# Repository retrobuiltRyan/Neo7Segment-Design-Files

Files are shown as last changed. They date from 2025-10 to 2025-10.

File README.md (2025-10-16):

KiCAD 8.x files created.

A reworked layout of Unexpected Maker's 7SegNeo Display project. Chain these addressable LED modules together to make a large 7-segment display. Control via any micro-controller just like you would control a strip of RGB LEDs. Custom library made by Unexpected Maker.



fart neo7seg good gif
P1100468

Assembly Required:
Each moduled has a resistor footprint at the Data In line. The first module in the chain requires a ~220-330 ohm resistor soldered here. Each moduled next in the chain requires this jumper closed; 0-ohm resistor or just a solder blob.
P1100470 - Copy

Change list: bumped-up passives footprint to 1206, finessed trace/ copper pour layout; slightly larger PCB area, larger mounting holes, decimal place pixel same footprint as all other pixels.
Created some 3D printable mounting brackets to expidite building projects like a clock/scoreboard. 

RGBLEDs: 1568-16347CT-ND or https://www.aliexpress.us/item/3256802466699315.html

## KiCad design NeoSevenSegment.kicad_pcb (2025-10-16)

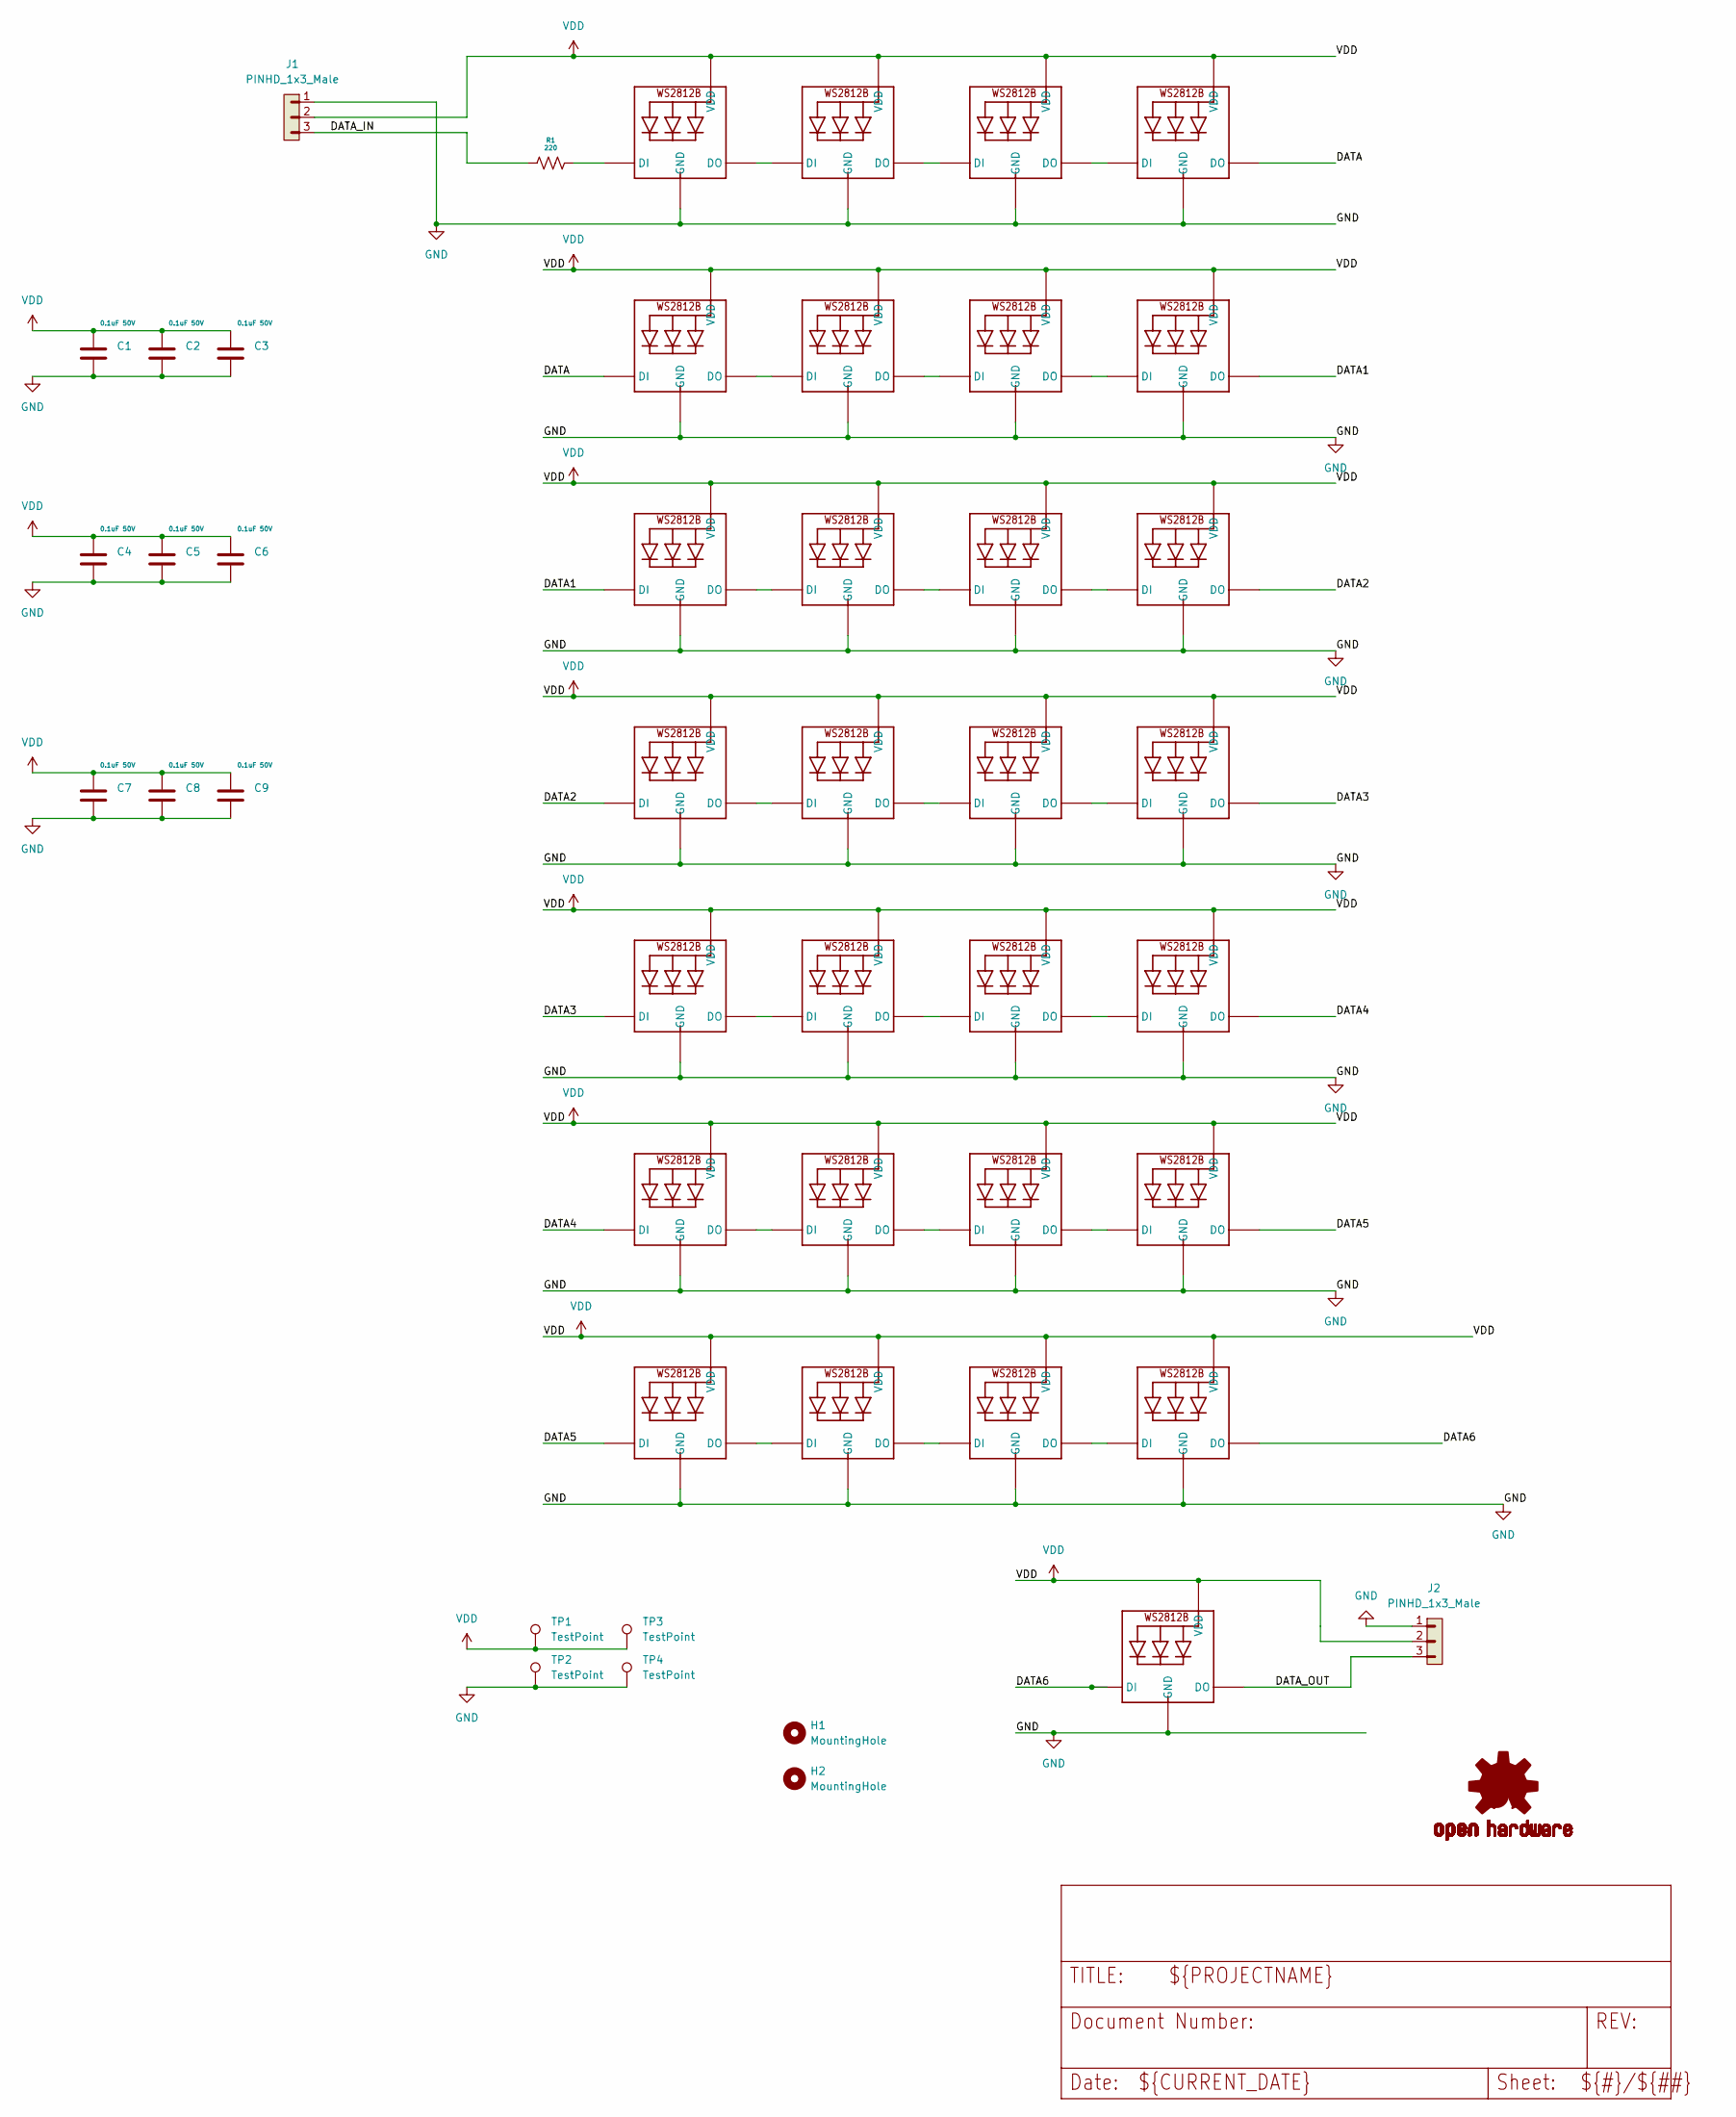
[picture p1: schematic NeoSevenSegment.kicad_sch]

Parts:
C1, C2, C3, C4, C5, C6, C7, C8, C9: 0.1uF 50V; C_1206_3216Metric; DigiKey P/N 1276-1068-1-ND
H1, H2: MountingHole; MountingHole_3.2mm_M3_ISO14580_Pad_TopBottom
J1, J2: PINHD_1x3_Male; PinHeader_1x03_P2.54mm_Vertical
LED1, LED2, LED3, LED4, LED5, LED6, LED7, LED8, LED9, LED10, LED11, LED12, LED13, LED14, LED15, LED16, LED17, LED18, LED19, LED20, LED21, LED22, LED23, LED24, LED25, LED26, LED27, LED28, LED29: WS2812B_5050N; WS2812B-NARROW
LOGO1: OSHW-LOGOM; OSHW-LOGO-M
R1: 220; R_1206_3216Metric; DigiKey P/N 311-220FRCT-ND
TP1, TP2, TP3, TP4: TestPoint; TestPoint_Pad_2.5x2.5mm

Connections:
/DATA: LED4.2-DOUT (DO), LED5.4-DIN (DI)
/DATA1: LED8.2-DOUT (DO), LED9.4-DIN (DI)
/DATA2: LED12.2-DOUT (DO), LED13.4-DIN (DI)
/DATA3: LED16.2-DOUT (DO), LED17.4-DIN (DI)
/DATA4: LED20.2-DOUT (DO), LED21.4-DIN (DI)
/DATA5: LED24.2-DOUT (DO), LED25.4-DIN (DI)
/DATA6: LED28.2-DOUT (DO), LED29.4-DIN (DI)
/DATA_IN: J1.3, R1.2
/DATA_OUT: J2.3, LED29.2-DOUT (DO)
GND: C1.2, C2.2, C3.2, C4.2, C5.2, C6.2, C7.2, C8.2, C9.2, J1.1, J2.1, LED1.3-GND (GND), LED2.3-GND (GND), LED3.3-GND (GND), LED4.3-GND (GND), LED5.3-GND (GND), LED6.3-GND (GND), LED7.3-GND (GND), LED8.3-GND (GND), LED9.3-GND (GND), LED10.3-GND (GND), LED11.3-GND (GND), LED12.3-GND (GND), LED13.3-GND (GND), LED14.3-GND (GND), LED15.3-GND (GND), LED16.3-GND (GND), LED17.3-GND (GND), LED18.3-GND (GND), LED19.3-GND (GND), LED20.3-GND (GND), LED21.3-GND (GND), LED22.3-GND (GND), LED23.3-GND (GND), LED24.3-GND (GND), LED25.3-GND (GND), LED26.3-GND (GND), LED27.3-GND (GND), LED28.3-GND (GND), LED29.3-GND (GND), TP2.1, TP4.1
unnamed: LED1.4-DIN (DI), R1.1
unnamed: LED1.2-DOUT (DO), LED2.4-DIN (DI)
unnamed: LED2.2-DOUT (DO), LED3.4-DIN (DI)
unnamed: LED3.2-DOUT (DO), LED4.4-DIN (DI)
unnamed: LED5.2-DOUT (DO), LED6.4-DIN (DI)
unnamed: LED6.2-DOUT (DO), LED7.4-DIN (DI)
unnamed: LED7.2-DOUT (DO), LED8.4-DIN (DI)
unnamed: LED9.2-DOUT (DO), LED10.4-DIN (DI)
unnamed: LED10.2-DOUT (DO), LED11.4-DIN (DI)
unnamed: LED11.2-DOUT (DO), LED12.4-DIN (DI)
unnamed: LED13.2-DOUT (DO), LED14.4-DIN (DI)
unnamed: LED14.2-DOUT (DO), LED15.4-DIN (DI)
unnamed: LED15.2-DOUT (DO), LED16.4-DIN (DI)
unnamed: LED17.2-DOUT (DO), LED18.4-DIN (DI)
unnamed: LED18.2-DOUT (DO), LED19.4-DIN (DI)
unnamed: LED19.2-DOUT (DO), LED20.4-DIN (DI)
unnamed: LED21.2-DOUT (DO), LED22.4-DIN (DI)
unnamed: LED22.2-DOUT (DO), LED23.4-DIN (DI)
unnamed: LED23.2-DOUT (DO), LED24.4-DIN (DI)
unnamed: LED25.2-DOUT (DO), LED26.4-DIN (DI)
unnamed: LED26.2-DOUT (DO), LED27.4-DIN (DI)
unnamed: LED27.2-DOUT (DO), LED28.4-DIN (DI)
VDD: C1.1, C2.1, C3.1, C4.1, C5.1, C6.1, C7.1, C8.1, C9.1, J1.2, J2.2, LED1.1-VDD (VDD), LED2.1-VDD (VDD), LED3.1-VDD (VDD), LED4.1-VDD (VDD), LED5.1-VDD (VDD), LED6.1-VDD (VDD), LED7.1-VDD (VDD), LED8.1-VDD (VDD), LED9.1-VDD (VDD), LED10.1-VDD (VDD), LED11.1-VDD (VDD), LED12.1-VDD (VDD), LED13.1-VDD (VDD), LED14.1-VDD (VDD), LED15.1-VDD (VDD), LED16.1-VDD (VDD), LED17.1-VDD (VDD), LED18.1-VDD (VDD), LED19.1-VDD (VDD), LED20.1-VDD (VDD), LED21.1-VDD (VDD), LED22.1-VDD (VDD), LED23.1-VDD (VDD), LED24.1-VDD (VDD), LED25.1-VDD (VDD), LED26.1-VDD (VDD), LED27.1-VDD (VDD), LED28.1-VDD (VDD), LED29.1-VDD (VDD), TP1.1, TP3.1

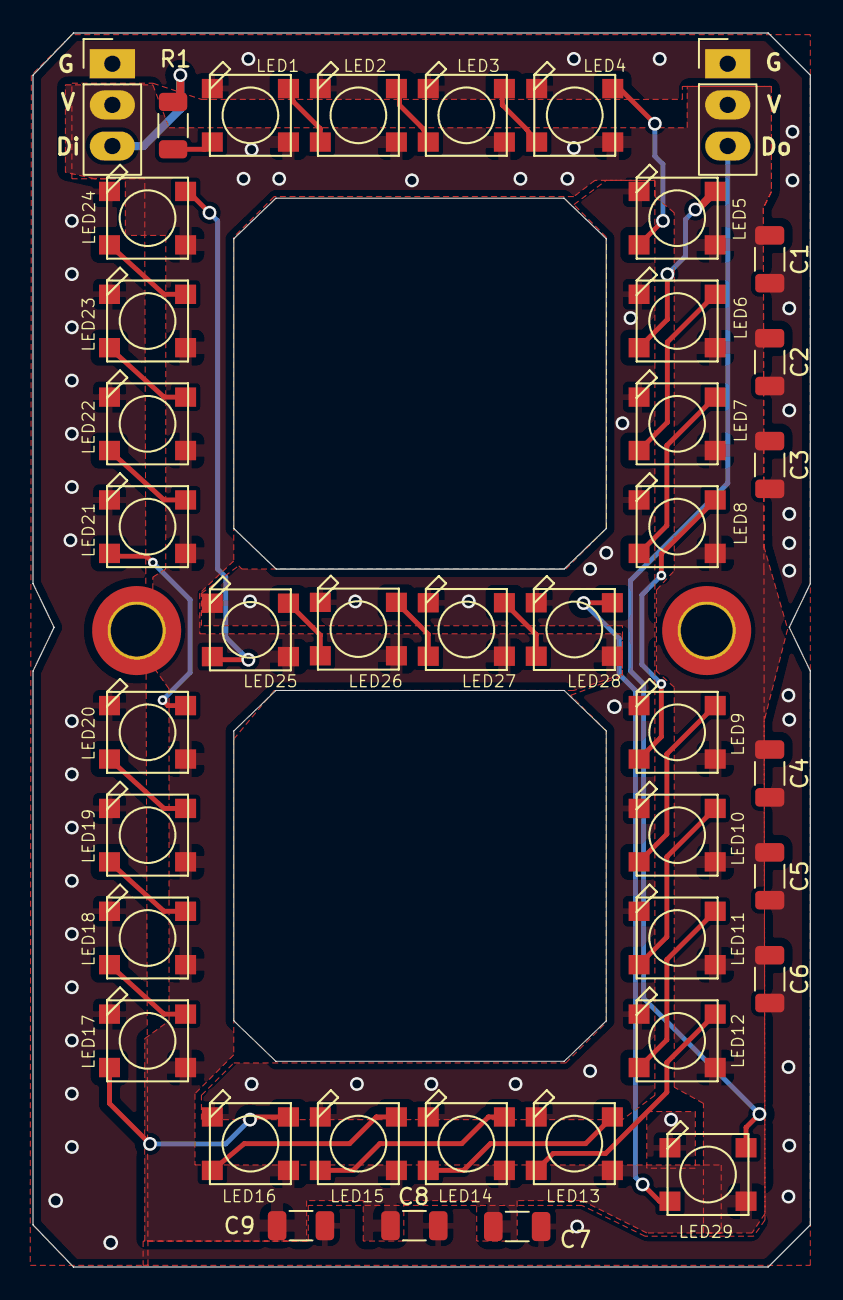
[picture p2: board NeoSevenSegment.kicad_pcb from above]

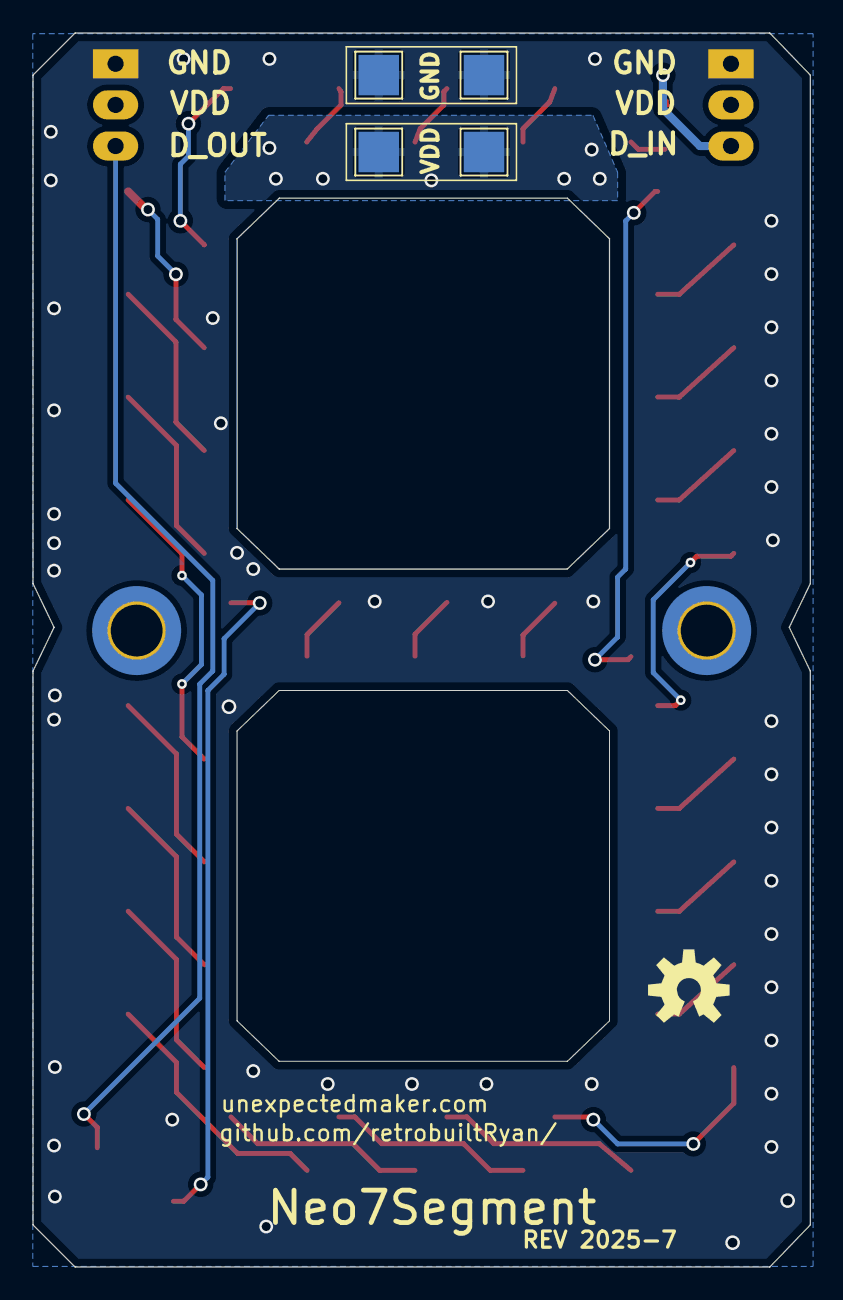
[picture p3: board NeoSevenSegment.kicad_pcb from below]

Board: 2 copper layers, 48.0 x 76.2 mm, 48 parts (5 on the bottom side), 33 nets.

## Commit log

2024-11-17 Eagle Design Files and Gerbers (ver Dec 2023)
    [NeoSevenSegment.brd, NeoSevenSegment.sch]
2025-07-30 design Files
    July 2025 revision. big copper pours for VDD and GND.
    [NeoSevenSegment.kicad_pcb, NeoSevenSegment.kicad_sch]
2025-10-16 design Files
    [NeoSevenSegment.kicad_pcb]
2025-10-16 gerbers
    JLCPCB tested
